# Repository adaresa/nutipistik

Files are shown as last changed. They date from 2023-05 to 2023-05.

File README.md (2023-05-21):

# Nutipistik

Nutipistik is an innovative smart plug solution designed and built entirely by me as a solo project. The motivation behind this project was my interest in promoting smarter and cost-efficient electricity usage. The project incorporates a multi-component architecture, utilizing various technologies and languages, including PHP, Python, CSS, C++, and JavaScript.

## Table of Contents

- [Components](#components)
  - [Analysis](#analysis)
  - [AWS](#aws)
  - [Hardware](#hardware)
  - [Webapp](#webapp)
- [Contributing](#contributing)

## Components

### Analysis

The Analysis component houses a Python script that serves as Nutipistik's financial advisor. It simulates and compares the total cost of three different electricity pricing strategies over a 12-month period, namely, a fixed electricity price, the daily average market price, and the 'Cheapest Hours' market price strategy. It then visualizes the resulting data on a line graph, providing a clear representation of cost changes over time.

### AWS

The AWS component comprises scripts hosted on Amazon Web Services. It undertakes the essential task of keeping the webapp's database updated with the latest electricity prices. In addition, it determines the appropriate state of the smart plugs based on their selected control mode and user-defined parameters.

### Hardware

The Hardware component encompasses all physical aspects of the Nutipistik project. It includes Case and PCB designs, 3D models of the complete hardware solution, as well as the Firmware running on the ESP12E microcontroller embedded in the PCB.

### Webapp

The Webapp component is the user interface of the Nutipistik project. It provides an interactive platform for users to control the smart plug system effectively. 

## Contributing

As a solo developer, I welcome any contributions! Whether you have feature requests, bug fixes, or any other improvements, please feel free to submit a pull request or open an issue. Your help in making Nutipistik better is greatly appreciated!

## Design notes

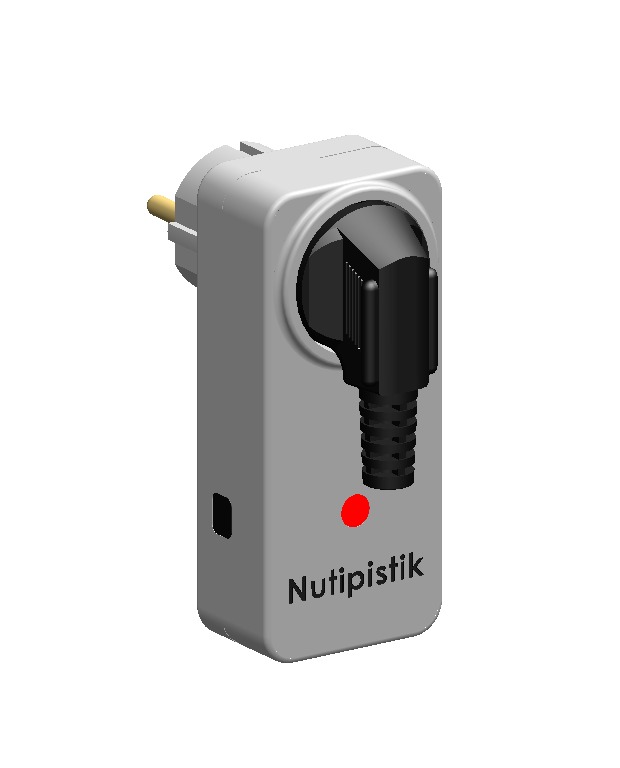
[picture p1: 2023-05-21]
hardware/Nutipistik Hardware.jpeg

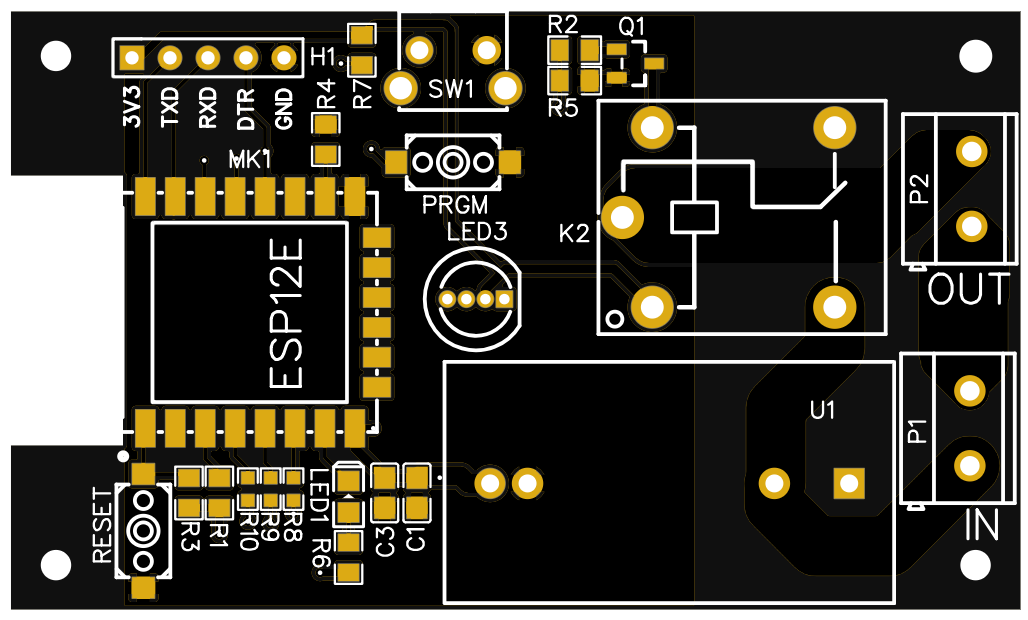
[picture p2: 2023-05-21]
hardware/pcb/design/Nutipistik PCB.png

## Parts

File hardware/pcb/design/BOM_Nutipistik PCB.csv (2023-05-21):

ID | Name | Designator | Footprint | Quantity | Manufacturer Part | Manufacturer | Supplier | Supplier Part | Price
1 | MHLA5319URGBDWT | LED3 | LED-TH_4P-BD6.9-P1.27-R | 1 | MHLA5319URGBDWT | MEIHUA(美华) | LCSC | C417349 | 0.318
2 | 1825027-8 | SW1 | KEY-TH_1825027-8 | 1 | 1825027-8 | TE Connectivity(美国泰科) | LCSC | C266196 | 0.128
3 | 10k | R7,R4,R1,R3,R5 | R0805 | 5 | RC0805FR-0710KL | YAGEO(国巨) | LCSC | C84376 | 0.002
4 | 220R | R8,R9,R10 | R0603 | 3 | RC0603FR-07220RL | YAGEO(国巨) | LCSC | C107696 | 0.001
5 | 10u | C1 | C0805 | 1 | C0805B106K025T | IHHEC(禾伸堂) | LCSC | C172703 | 0.083
6 | 0.1u | C3 | C0805 | 1 | C0805C104K5RAC7800 | KEMET(基美) | LCSC | C75414 | 0.02
7 | SRD-03VDC-SL-C | K2 | RELAY-TH_SRD-XXVDC-XL-C | 1 | SRD-03VDC-SL-C | 松乐 | LCSC | C24585 | 0.442
8 | LED-0805_B | LED1 | LED0805_BLUE | 1 | D-B080508B1-KS2 | 方舟 ARKLED |  | C108412 | 0.012
9 | 2.4GHz | MK1 | WIFIM-SMD_ESP-12E-BR | 1 | ESP-12E | Ai-Thinker(安信可) | LCSC | C89297 | 2.617
10 | CONN-TH_2P-P5.00 | P1,P2 | CONN-TH_2P-P5.00 | 2 | DB126V-5.0-2P-GN-P | DIBO(地博电气) | LCSC | C395849 | 0.092
11 | 2N3904(SOT-23) | Q1 | SOT-23-3_L2.9-W1.3-P1.90-LS2.4-TR | 1 | 2n3904S-RTK/PS | KEC | LCSC | C18536 | 0.013
12 | 1k | R2,R6 | R0805 | 2 | CR0805F81001G | LIZ(丽智电子) | LCSC | C101404 | 0.002
13 | HLK-2M03 | U1 | PWRM-TH_HLK-2M03 | 1 | HLK-2M03 | HI-LINK(海凌科) | LCSC | C399249 | 2.681
14 | K2-3.6×6.1_SMD | PRGM,RESET | KEY-SMD_2P-L6.2-W3.6-LS8.0 | 2 | K2-1107ST-A4SW-06 |  | LCSC | C118141 | 0.069
15 | HDR-F-2.54_1x5 | H1 | HDR-F-2.54_1X5 | 1 |  |  | LCSC | C50950 | 0.06

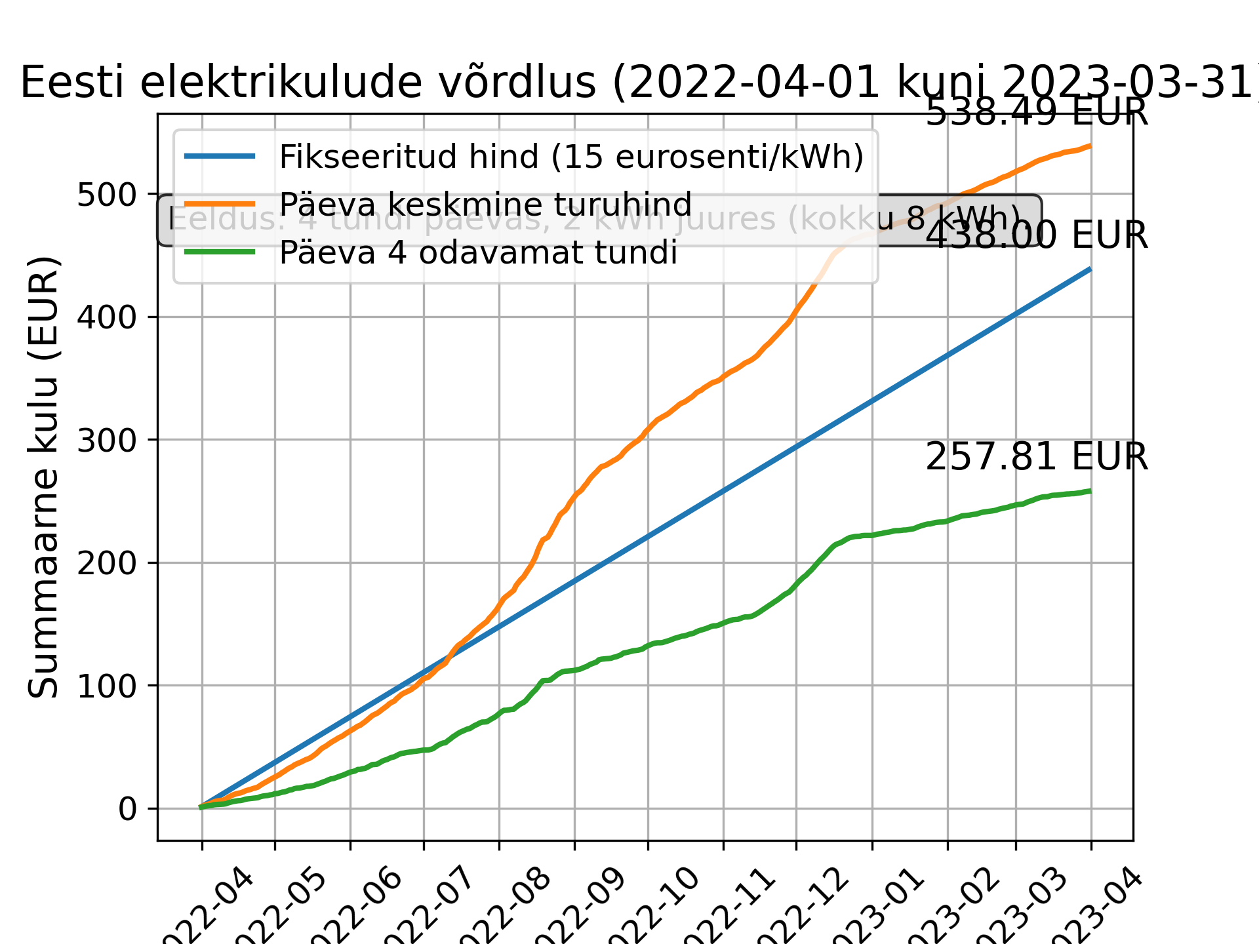
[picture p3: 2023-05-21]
analysis/electricity_costs.png

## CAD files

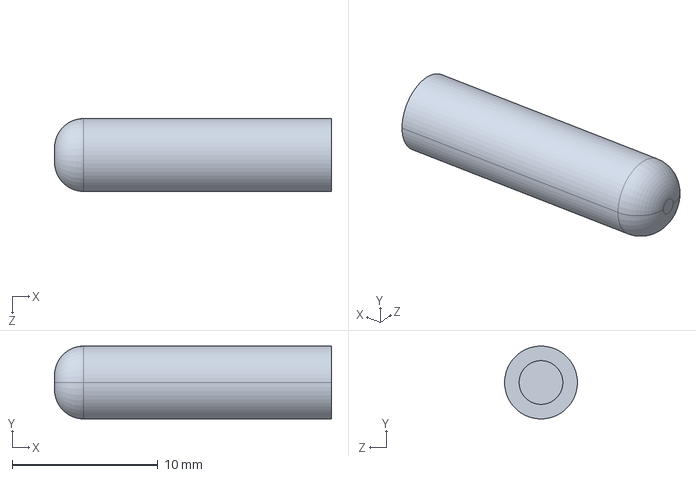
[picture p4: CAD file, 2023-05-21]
hardware/brass connectors/M3 brass pins.STEP
19.0 x 5.00 x 5.00 mm

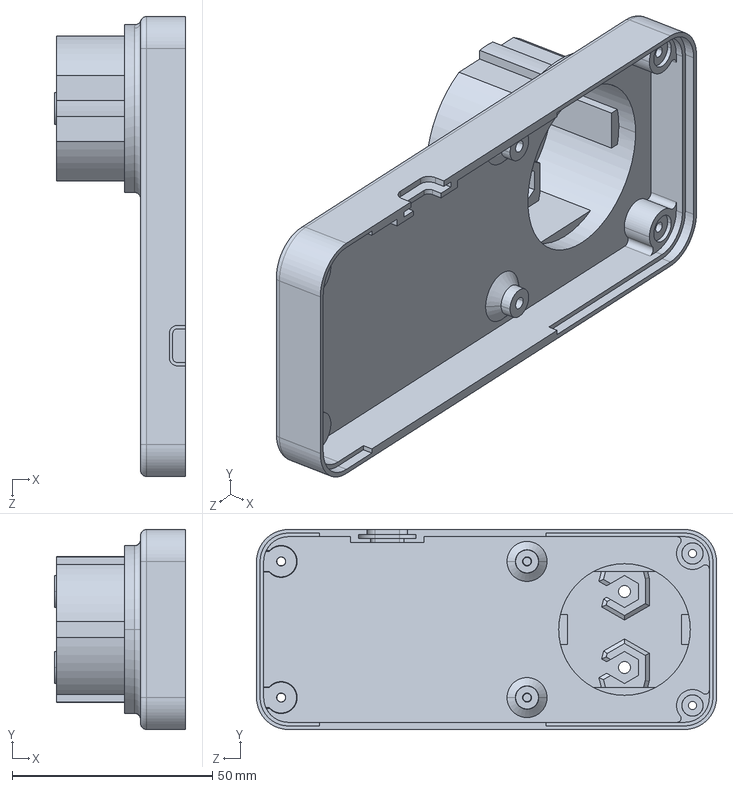
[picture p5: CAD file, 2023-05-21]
hardware/case/SMG Smart Plug Base V1.1.STEP
32.8 x 50.0 x 115.0 mm

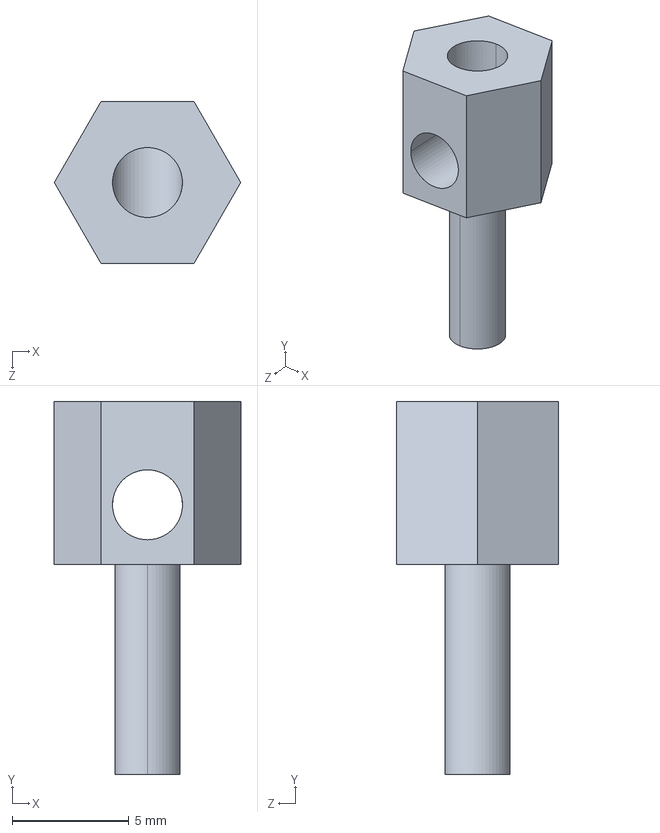
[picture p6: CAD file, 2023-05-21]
hardware/brass connectors/M3 Brass Pin for bottom connection.STEP
8.00 x 16.0 x 6.93 mm

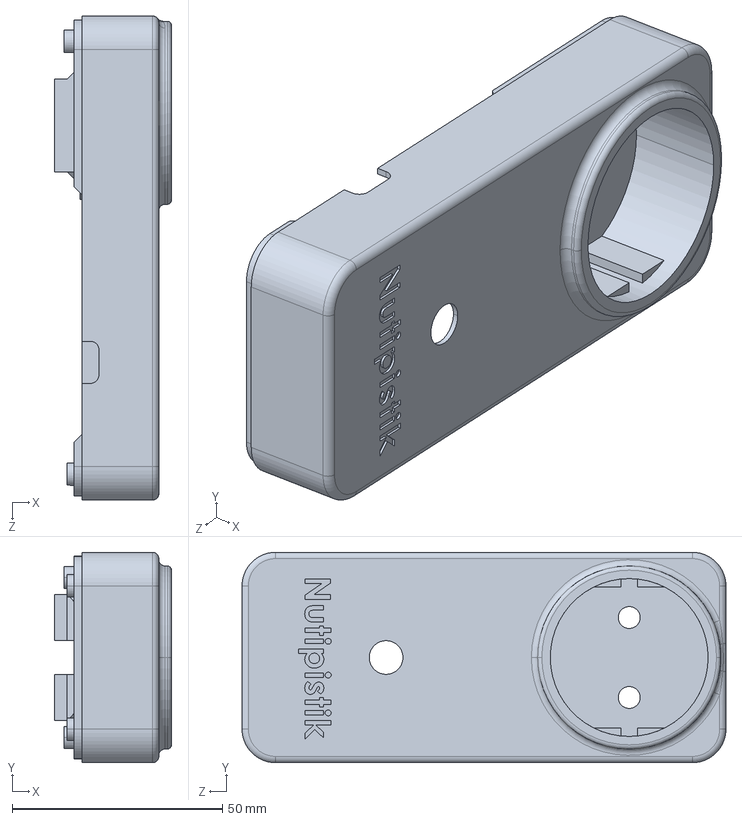
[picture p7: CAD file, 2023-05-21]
hardware/case/SMG Smart Plug Case V1.1.STEP
27.8 x 50.0 x 115.0 mm

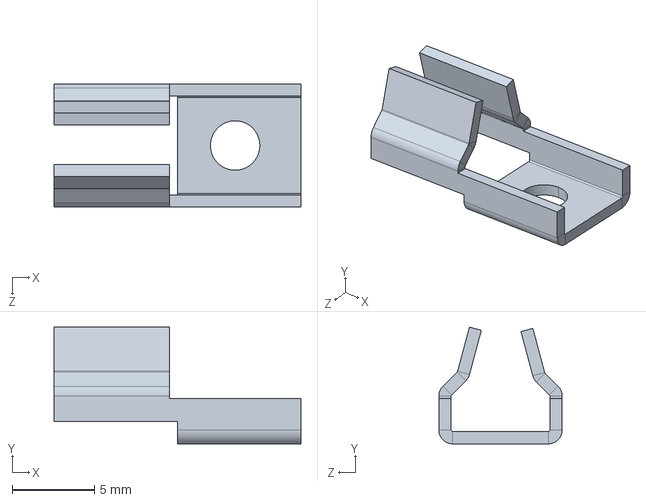
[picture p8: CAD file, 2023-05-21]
hardware/brass connectors/M3 Brass Sheet metal Connector.STEP
15.0 x 7.09 x 7.50 mm

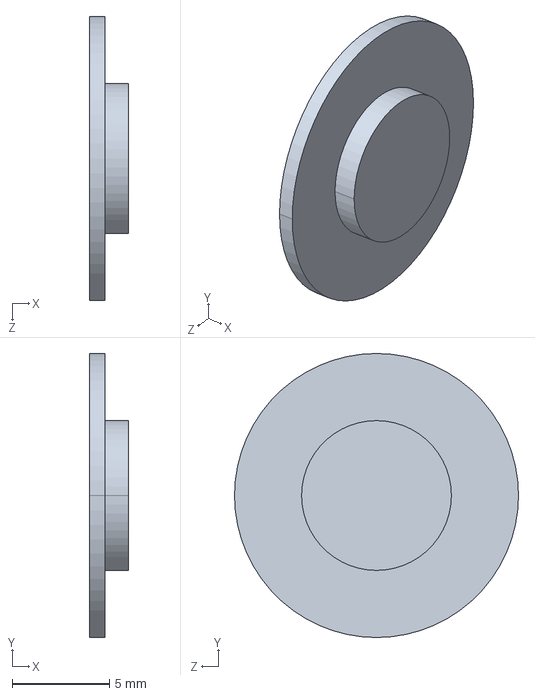
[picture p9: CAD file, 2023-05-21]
hardware/case/SMG Smart Plug LED V1.1.STEP
2.00 x 14.6 x 14.6 mm

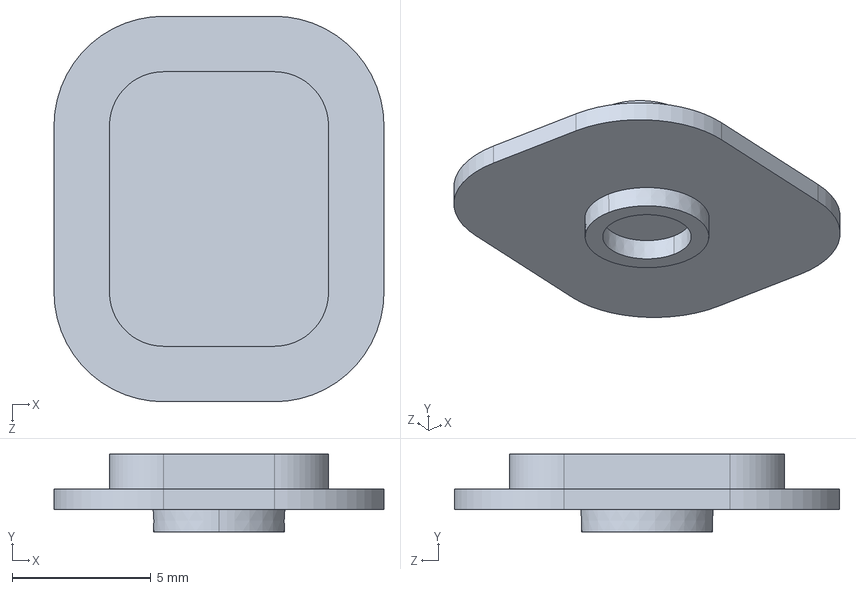
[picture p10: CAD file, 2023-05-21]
hardware/case/SMG Smart Plug Switch V1.1.STEP
11.9 x 2.80 x 13.9 mm

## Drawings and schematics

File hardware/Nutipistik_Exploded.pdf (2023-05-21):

2

8

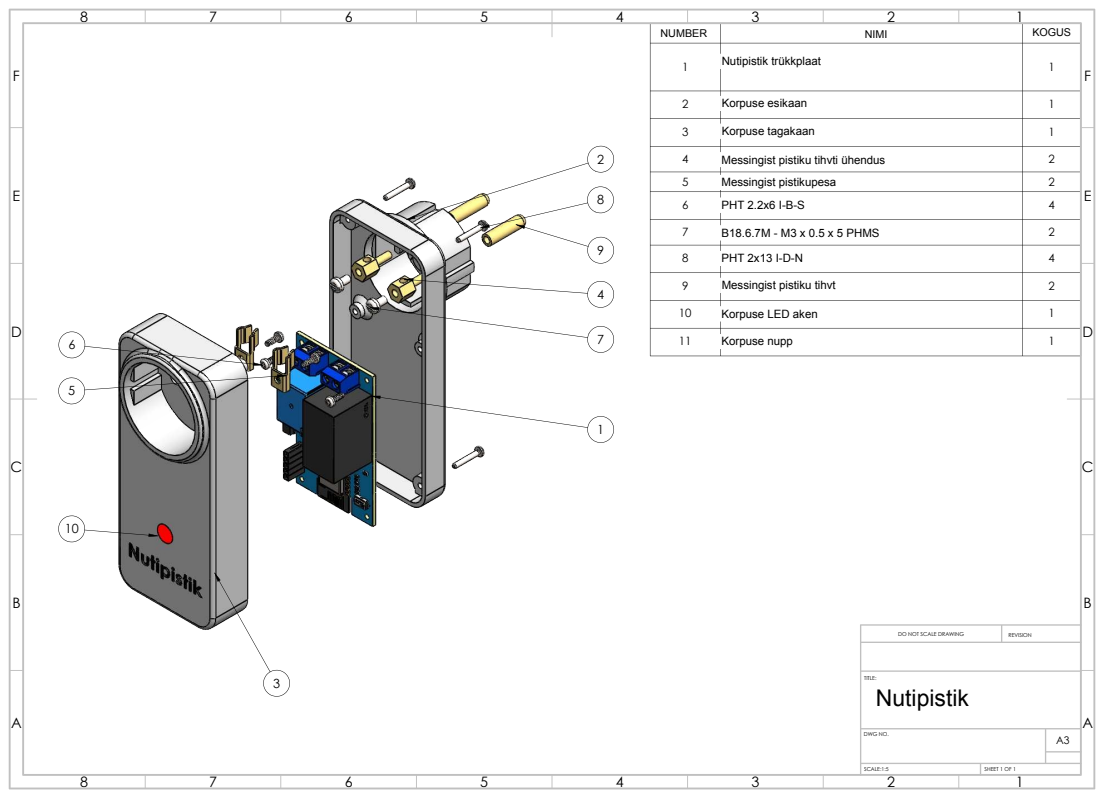
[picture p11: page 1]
DO NOT SCALE DRAWING; REVISION; TITLE:; DWG NO.; SCALE:1:5; SHEET 1 OF 1; NUMBER; NIMI; KOGUS; Nutipistik trükkplaat; Korpuse esikaan; Korpuse tagakaan; Korpuse nupp; Nutipistik; PHT 2x13 I-D-N; B18.6.7M - M3 x 0.5 x 5 PHMS; PHT 2.2x6 I-B-S; Messingist pistikupesa

Messingist pistiku tihvti ühendus

Messingist pistiku tihvt

Korpuse LED aken

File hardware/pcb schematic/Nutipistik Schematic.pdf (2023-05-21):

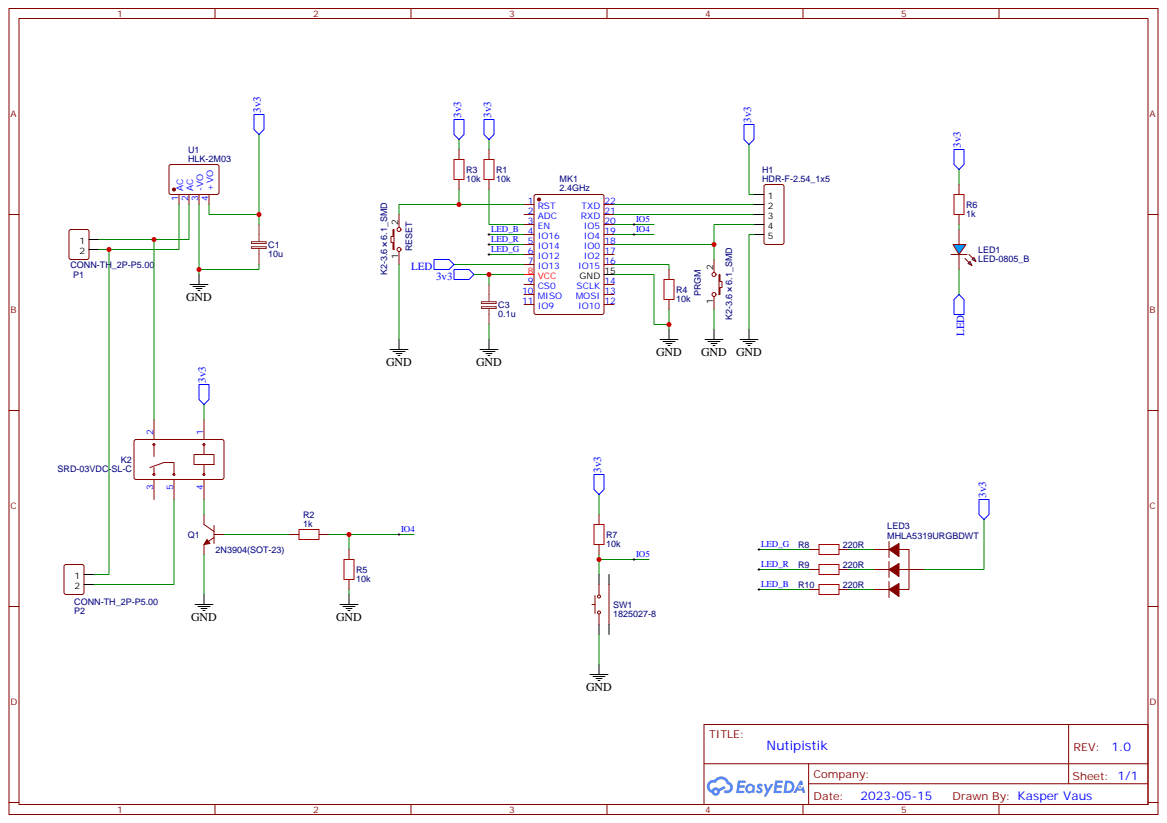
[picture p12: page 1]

Drawn By: Kasper Vaus

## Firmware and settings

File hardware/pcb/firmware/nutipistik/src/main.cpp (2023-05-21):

#include <Arduino.h>
#include <ESP8266WiFi.h>
#include <WiFiManager.h>
#include <ESP8266HTTPClient.h>
#include <WiFiClientSecureBearSSL.h>
#include "secrets.h"

// Uncomment the following line to enable debug prints
#define DEBUG

#ifdef DEBUG
#define DEBUG_PRINT(...) Serial.print(__VA_ARGS__)
#define DEBUG_PRINTLN(...) Serial.println(__VA_ARGS__)
#else
#define DEBUG_PRINT(...)
#define DEBUG_PRINTLN(...)
#endif

// Constants
constexpr uint32_t RECONNECT_TIMEOUT = 5000; // Time in milliseconds to wait before attempting to reconnect
const char CONFIG_SSID[] = "Nutipistik";     // SSID for configuration portal

// Pin definitions
constexpr uint8_t RELAY_PIN = 4;
constexpr uint8_t BUTTON_PIN = 5;
constexpr uint8_t RGBLED_R_PIN = 16;
constexpr uint8_t RGBLED_G_PIN = 14;
constexpr uint8_t RGBLED_B_PIN = 12;
constexpr uint32_t DEBOUNCE_DELAY = 50; // Debounce delay in milliseconds

// Variables
uint32_t lastConnectAttempt = 0;
bool systemActive = true;
bool buttonHeld = false;
volatile bool lastButtonState = true;
volatile uint32_t lastButtonChangeTime = 0;
volatile uint32_t buttonPressTime = 0;
volatile bool buttonPressed = false;

String deviceIdText = "<p>Pistiku id: <b>" + String(DEVICE_ID) + "</b></p>";
WiFiManagerParameter deviceIdParam(deviceIdText.c_str());

String devicePasswordText = "<p>Pistiku Salasõna: <b>" + String(DEVICE_PASSWORD) + "</b></p>";
WiFiManagerParameter devicePasswordParam(devicePasswordText.c_str());

// Function prototypes
void connectToWiFi();
void controlLed(const bool red, const bool green, const bool blue);
void IRAM_ATTR handleButtonChange();
void checkRelayState();

// flag for saving data
bool shouldSaveConfig = false;

// callback notifying us of the need to save config
void saveConfigCallback()
{
  shouldSaveConfig = true;
}

// Connect to WiFi or keep trying to reconnect if not connected.
void connectToWiFi()
{
  WiFiManager wifiManager;
  wifiManager.addParameter(&deviceIdParam);
  wifiManager.addParameter(&devicePasswordParam);

  wifiManager.setSaveConfigCallback(saveConfigCallback);

  DEBUG_PRINTLN("Connecting to WiFi");

  // Check for existing credentials
  if (WiFi.status() == WL_CONNECTED)
  {
    DEBUG_PRINTLN("WiFi connected");
    return;
  }

  // Check if no credentials are saved
  String savedSSID = WiFi.SSID();
  if (savedSSID.length() == 0)
  {
    DEBUG_PRINTLN("No saved WiFi credentials");
    controlLed(false, false, true);
    if (wifiManager.startConfigPortal(CONFIG_SSID))
    {
      DEBUG_PRINTLN("Config portal closed");
    }
    return;
  }

  // Try to connect to saved credentials
  DEBUG_PRINTLN("Trying to connect to saved WiFi credentials");
  WiFi.begin(savedSSID.c_str(), WiFi.psk().c_str());

  // Wait for the connection to be established with a series of short delays
  unsigned long startTime = millis();
  unsigned long maxWaitTime = 10000;
  unsigned long delayInterval = 100;
  while (WiFi.status() != WL_CONNECTED && (millis() - startTime) < maxWaitTime)
  {
    delay(delayInterval);
  }
  // If connection is successful, blink LED 3 times to indicate successful connection
  if (WiFi.status() == WL_CONNECTED)
  {
    DEBUG_PRINTLN("WiFi connected");
    for (uint8_t i = 0; i < 3; i++)
    {
      controlLed(false, true, true);
      delay(200);
      controlLed(false, false, false);
      delay(200);
    }
  }

  lastConnectAttempt = millis();
}

void controlLed(const bool red, const bool green, const bool blue)
{
  digitalWrite(RGBLED_R_PIN, red ? LOW : HIGH);
  digitalWrite(RGBLED_G_PIN, green ? LOW : HIGH);
  digitalWrite(RGBLED_B_PIN, blue ? LOW : HIGH);
}

void IRAM_ATTR handleButtonChange()
{
  uint32_t currentTime = millis();

  if (currentTime - lastButtonChangeTime > DEBOUNCE_DELAY)
  {
    lastButtonChangeTime = currentTime;

    bool buttonState = digitalRead(BUTTON_PIN);
    if (buttonState == LOW)
    {
      // Button press
      buttonPressTime = currentTime;
      buttonPressed = true;
    }
    else
    {
      // Button release
      if (buttonPressed)
      {
        uint32_t pressDuration = currentTime - buttonPressTime;
        buttonPressed = false;

        if (pressDuration > 2000)
        {
          // Button held for more than 2 seconds
          DEBUG_PRINTLN("Button held");
          buttonHeld = true;
        }
        else
        {
          systemActive = !systemActive;
          DEBUG_PRINTLN("Button pressed");
          DEBUG_PRINTLN(systemActive ? "System active" : "System inactive");

          // Handle button press
          if (!systemActive)
          {
            digitalWrite(RELAY_PIN, LOW);
            controlLed(false, false, false); // Turn off LED
          }
        }
      }
    }
  }
}

void checkRelayState()
{
  // Make HTTP GET request to server
  HTTPClient http;
  BearSSL::WiFiClientSecure client;

  String requestUrl = String("https://nutipistik.fun/RX.php?id=") + String(DEVICE_ID) + String("&pw=") + String(DEVICE_PASSWORD);

  client.setInsecure();
  http.begin(client, requestUrl);

  int httpCode = http.GET();

  if (httpCode == HTTP_CODE_OK)
  {
    String response = http.getString();

    if (!systemActive)
    {
      return;
    }

    if (response == "#1")
    {
      // Turn relay ON
      digitalWrite(RELAY_PIN, HIGH);
      controlLed(false, true, false); // Set LED to green
    }
    else if (response == "#0")
    {
      // Turn relay OFF
      digitalWrite(RELAY_PIN, LOW);
      controlLed(true, false, false); // Set LED to red
    }
    else
    {
      // Invalid data, set LED to purple
      controlLed(true, false, true);
    }

    DEBUG_PRINTLN(response);
    delay(2500);
  }
  else
  {
    // Log error message and wait before retrying
    controlLed(true, false, true);
    DEBUG_PRINT("HTTP GET request failed with error code: ");
    DEBUG_PRINTLN(httpCode);
    delay(5000);
  }

  http.end();
}

void setup()
{
  Serial.begin(115200);

  attachInterrupt(digitalPinToInterrupt(BUTTON_PIN), handleButtonChange, CHANGE);

  pinMode(RELAY_PIN, OUTPUT);
  pinMode(BUTTON_PIN, INPUT_PULLUP);
  pinMode(RGBLED_R_PIN, OUTPUT);
  pinMode(RGBLED_G_PIN, OUTPUT);
  pinMode(RGBLED_B_PIN, OUTPUT);

  controlLed(false, true, true); // cyan - connecting to WiFi
  connectToWiFi();
}

void loop()
{
  if (!systemActive)
  {
    return;
  }

  if (buttonHeld)
  {
    DEBUG_PRINTLN("Resetting WiFi credentials");

    // Disconnect and erase credentials
    WiFi.disconnect(true);
    ESP.eraseConfig();

    // Reset WiFiManager settings
    WiFiManager wifiManager;
    wifiManager.resetSettings();

    controlLed(false, true, false); // Set LED to blue
    connectToWiFi();
  }

  if (WiFi.status() != WL_CONNECTED)
  {
    if (millis() - lastConnectAttempt > RECONNECT_TIMEOUT)
    {
      controlLed(false, true, true); // Set LED to cyan
      connectToWiFi();
    }
  }
  else
  {
    checkRelayState();
  }
}

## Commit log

2022-10-14 Implement logic for different controlTypes
    * possibility to function as a regular switch / comparing price to pricelimit
2022-10-14 Comment out print
2022-10-14 Remove output logic from Arduino
2022-10-22 Add Cheapest Hours control type
    * Set arduino to switch digital pin 7 (relay) in addition to LED
    * Add Cheapest Hours option to Control Types -> ON in the cheapest X hours
2023-03-17 PCB Solution v1
    * Include initial code for controlling switch with PCB
    * Webapp formatting, including line graph into price_tabel
2023-03-19 Socket state tooltip
    * Added tooltip next to Socket state
    * Added optional parameter to protectTooltip to stop it from being deleted
2023-03-24 Added profile page
    * Added profile page to view username, device_id and change password
    * Updated style of settings
    * Tooltip wrap on multiple lines when small window
2023-03-25 Update look for Price Limit control type
    * Show current electricity price
    * Show days average electricity price
    * Define unit in input field
2023-04-02 Allow multiple devices per account
    * Allows multiple devices per account
    * Added dropdown to panel to select between devices
    * REGION, VAT, ELECTRICITY_TYPE now account-based, not device-based.
    * Fixed prices for today/tomorrow being swapped
2023-04-04 Add device managing
    * Allow the user to add/delete/edit devices
    * Optimize updateOutput
2023-04-06 Update ESP code
    * Code for PCB with RGB led and Button
    * Password needed for adding new device
    * ID and Password shown for device in its WifiManager
2023-04-09 Enable account registering
    * Add register form for new users to create an account
    * Add informative tooltips for setting up first device
2023-04-14 Schedule fix
    * Fix the Submit button in the Schedule Control Mode
    * Adjust the daily consumption in the analysis to be 8kW per day
2023-04-15 Reset device settings
    * Reset device settings when:
    * Removing user device
    * Deleting user account (attached devices get reset)
2023-05-21 Include all files
    * Include hardware files & design
    * Rename 'arduino' to 'firmware' and move under hardware section
    [BOM_Nutipistik PCB.csv, M3 Brass Pin for bottom connection.STEP, M3 Brass Sheet metal Connector.STEP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]
